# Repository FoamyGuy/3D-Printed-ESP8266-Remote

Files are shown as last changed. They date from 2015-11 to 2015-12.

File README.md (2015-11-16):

# 3D Printed Box for ESP8266 Remote Control

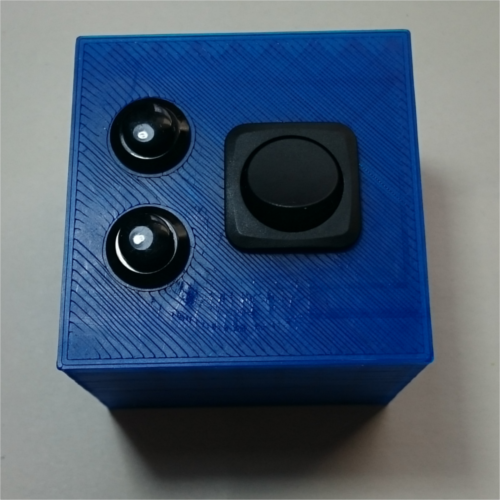
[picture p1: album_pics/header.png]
Main Image


[Picture Album](http://imgur.com/a/LUhH1)

This is a little box I designed to hold an ESP8266 powered remote control. It features 2 buttons, an on/off switch, and a 3v CR123A battery.

### Parts List:
- Box
- Lid
- Divider Plate
- Smallish Piece of Proto-board
- Braided copper wire
- CR123A 3v Battery
- Copper tape
- ESP8266
- 2x Brass 8-32 Threaded Inserts
- 2x 8-32 Machine screws 3/8" length

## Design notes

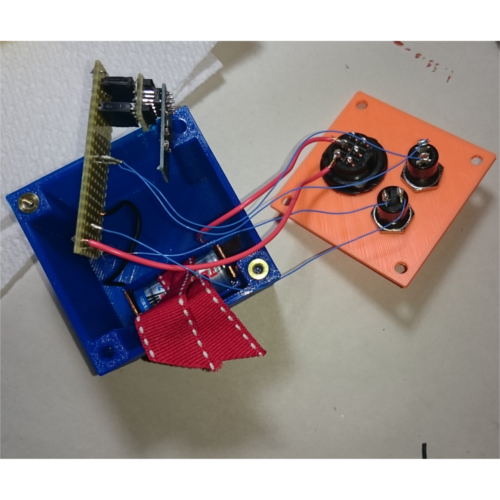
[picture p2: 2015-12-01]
album_pics/2_part_design.png

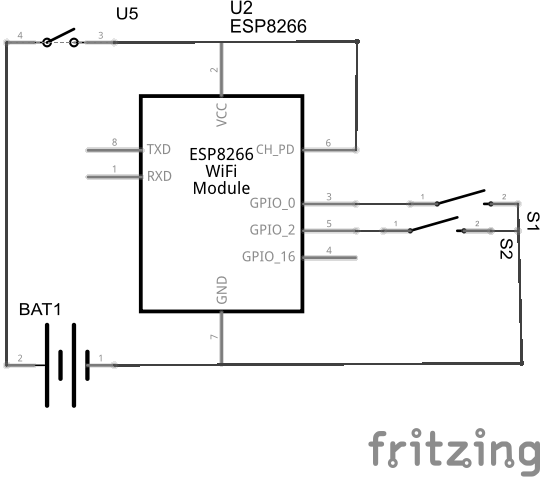
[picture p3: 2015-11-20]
album_pics/schematic.png

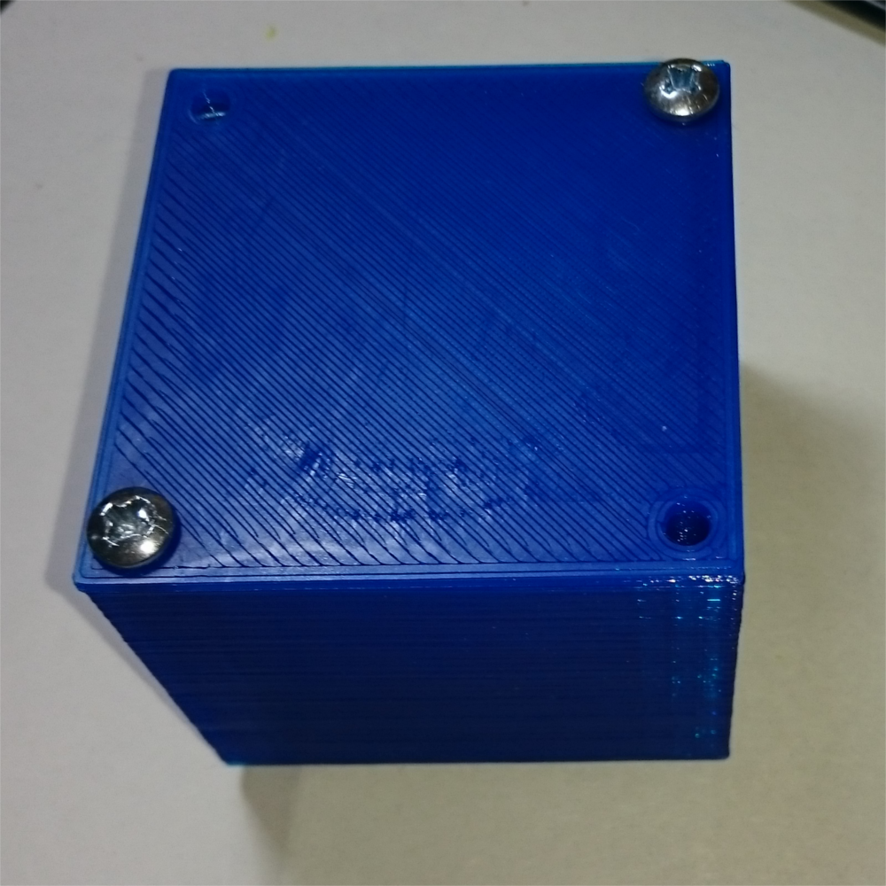
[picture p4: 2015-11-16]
album_pics/with_lid.png

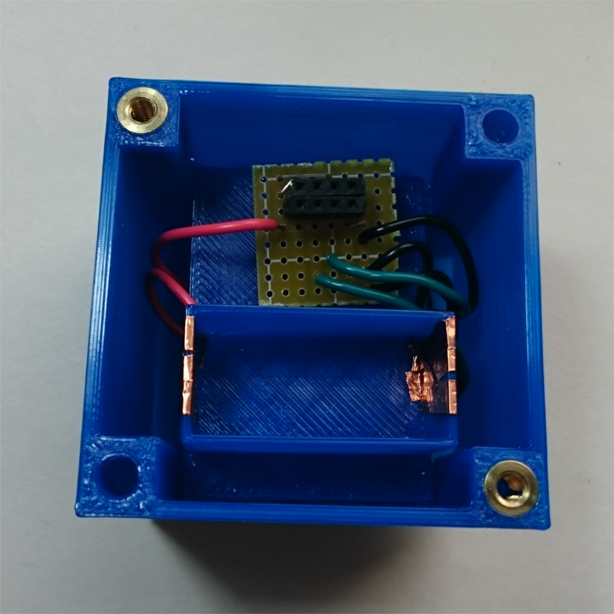
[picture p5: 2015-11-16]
album_pics/battery_conteacts_board.png

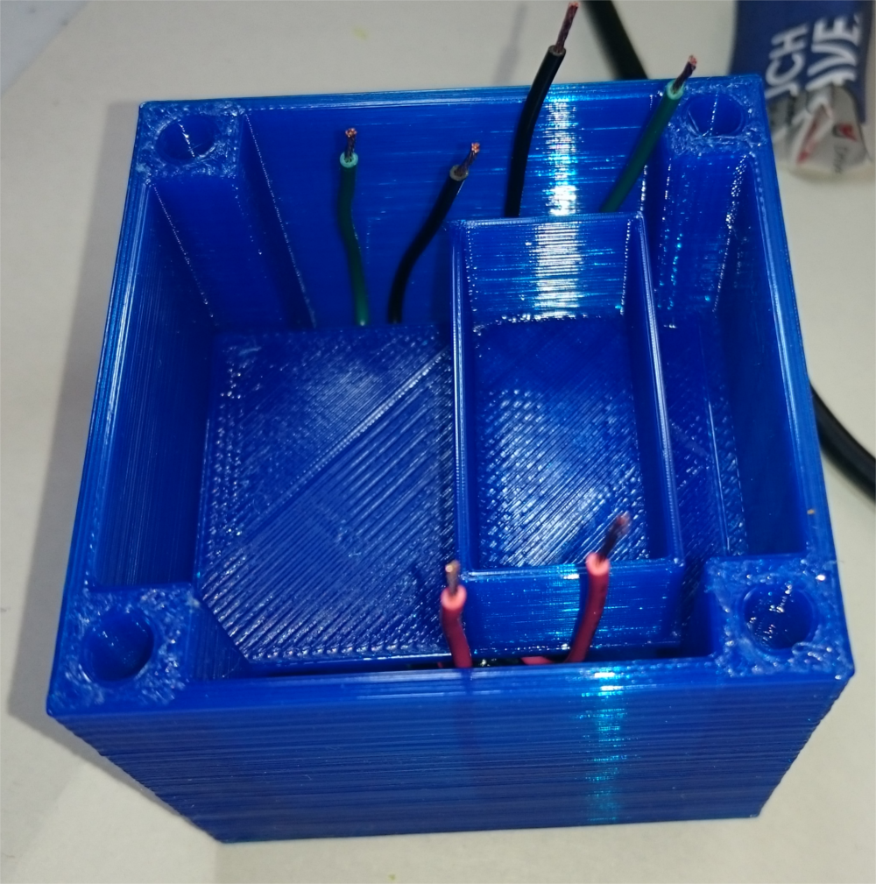
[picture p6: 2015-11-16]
album_pics/divider_in.png

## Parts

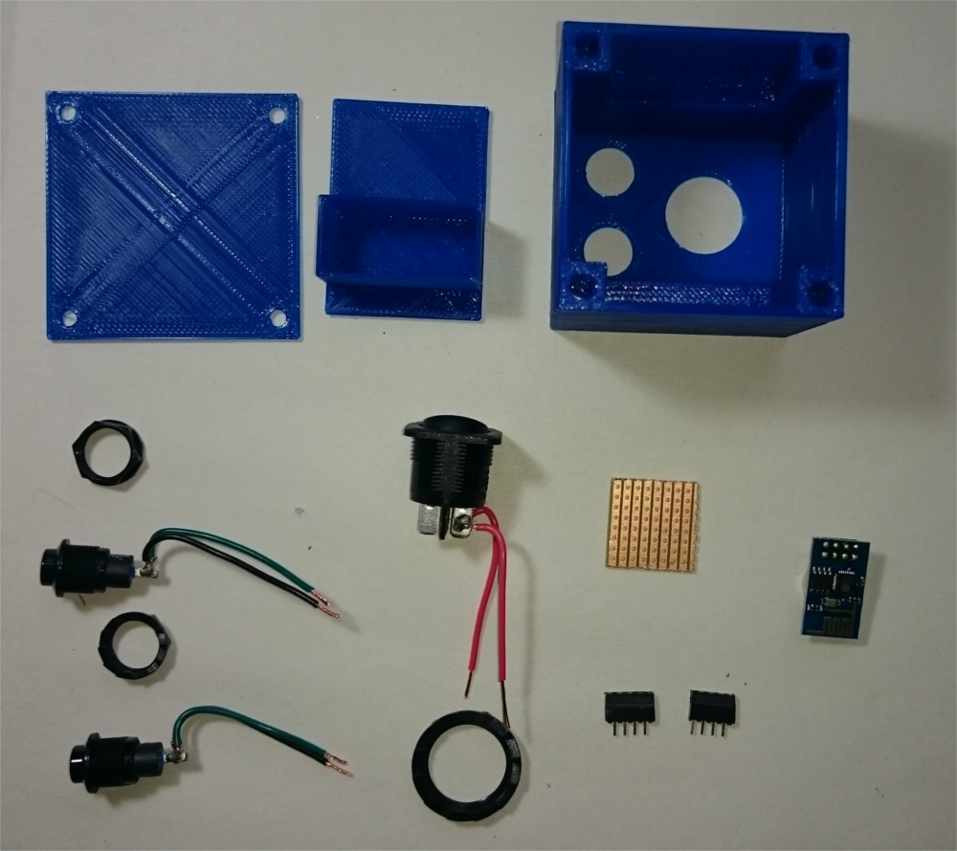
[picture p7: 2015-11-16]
album_pics/parts.png

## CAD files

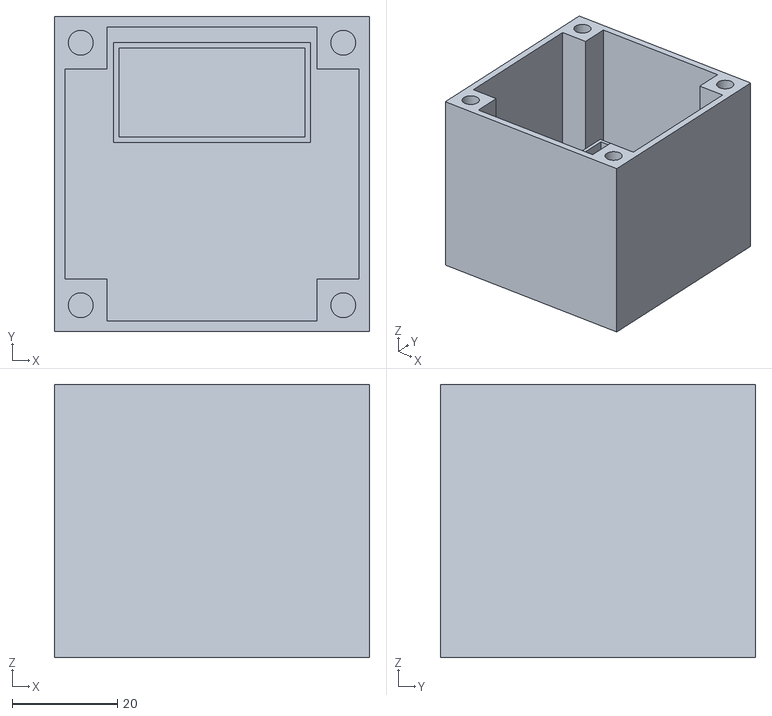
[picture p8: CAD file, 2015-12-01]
esp_box_v3.stl
60.0 x 60.0 x 52.0

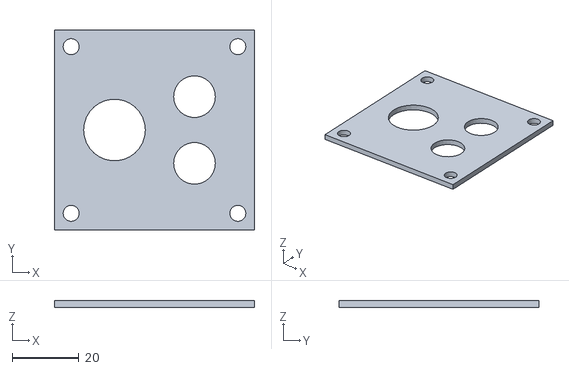
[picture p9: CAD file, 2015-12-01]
esp_box_v3_lid.stl
60.0 x 60.0 x 2.00

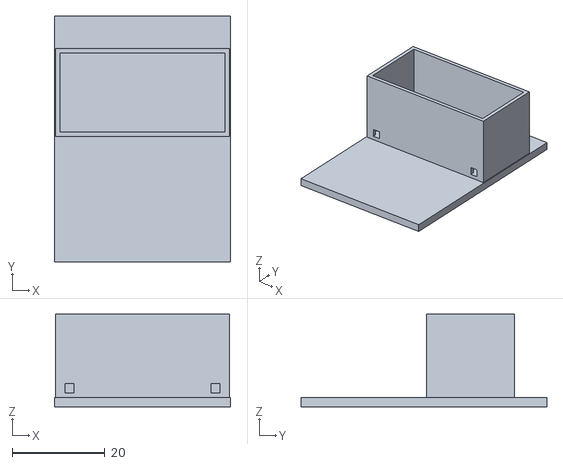
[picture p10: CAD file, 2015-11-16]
esp_box_divider.stl
38.0 x 53.0 x 20.0

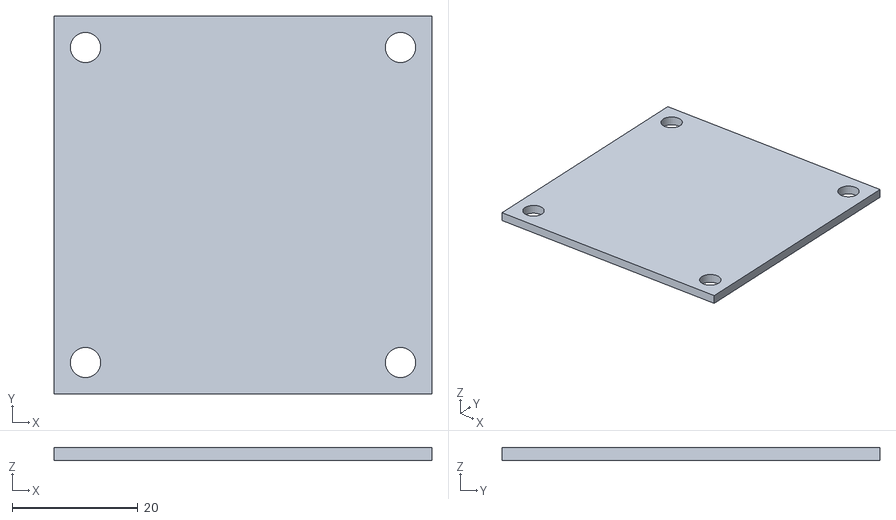
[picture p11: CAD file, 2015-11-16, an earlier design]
esp_box_lid.stl
60.0 x 60.0 x 2.00

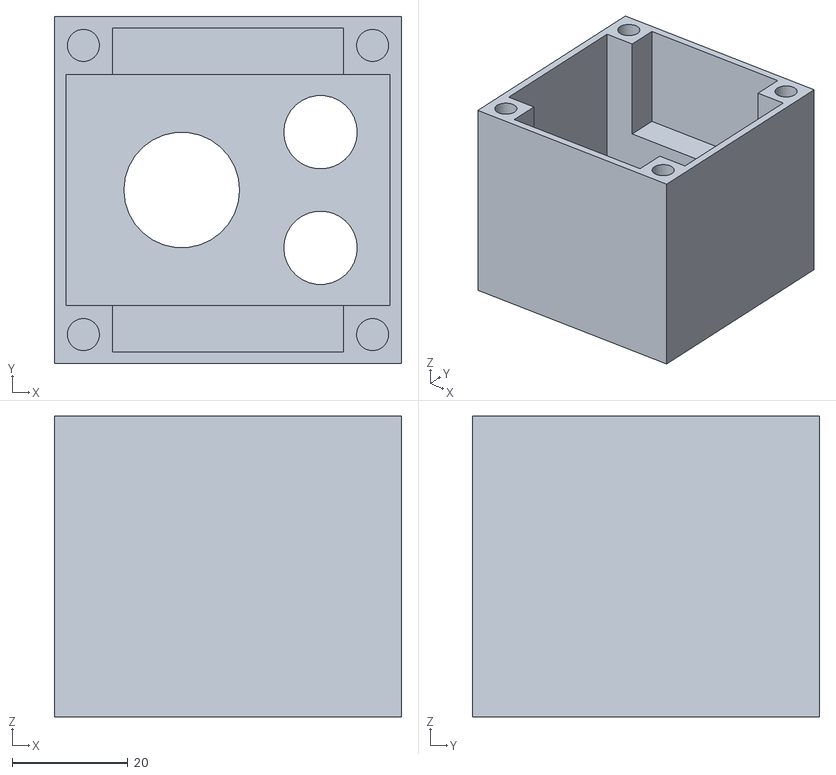
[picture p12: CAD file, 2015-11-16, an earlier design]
esp_box.stl
60.0 x 60.0 x 52.0

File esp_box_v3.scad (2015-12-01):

/**************************************************
    Variables
***************************************************/
$fn=30;

WALL_THICKNESS = 2;
BOTTOM_THICKNESS = 1;

POST_SIZE = 15;

BOARD_X = 30;
BOARD_Y = 60;
BOARD_Z = 18;

BOX_X = 60;
BOX_Y = 60;
BOX_Z = 52;

BAT_Y = 19;
BAT_X = 37.5;
BAT_Z = 19;

SWITCH_DRILL_DIAMETER = 18.5;
BUTTON_DRILL_DIAMETER = 12.5;

STANDOFF_SIZE = 10;

DIVIDER_STANDOFF_HEIGHT = 25;

INSERT_DRILL_DIAMETER = 4.7625;

/**************************************************
    Modules
***************************************************/

module box_bottom(l, w, h, wall_thickness=1, bottom_thickness=1){
    difference(){
        cube([l,w,h], center=true);
        translate([0,0,bottom_thickness])
            cube([l-(wall_thickness*2),w-(wall_thickness*2),h], center=true);
    
        //window to see in.
        //translate([0, w/2, h/2-2])cube([l-2, wall_thickness + 3, 34], center=true);
    }
}

module insert_post(h=10){
    difference(){
        cube([STANDOFF_SIZE, STANDOFF_SIZE, h], center=true);
        //translate([0,0, -h/2])cylinder(h=h, d=15);
        translate([0,0, (h/2)-12])cylinder(r=INSERT_DRILL_DIAMETER/2, h=12);
    }

}

module all_posts(BOX_X, BOX_Y, BOX_Z, wall_thickness=2){
    
    translate([BOX_X/2 - STANDOFF_SIZE/2, 
               BOX_Y/2 - STANDOFF_SIZE/2, 0])
        insert_post(BOX_Z);
    
    translate([-BOX_X/2 + STANDOFF_SIZE/2, 
               -BOX_Y/2 + STANDOFF_SIZE/2, 0])
        insert_post(BOX_Z);
    
    translate([-BOX_X/2 + STANDOFF_SIZE/2, 
               BOX_Y/2 - STANDOFF_SIZE/2, 0])
        insert_post(BOX_Z);
    
    translate([BOX_X/2 - STANDOFF_SIZE/2, 
               -BOX_Y/2 + STANDOFF_SIZE/2, 0])
        insert_post(BOX_Z);
}



module lid(l,w,h, wall_thickness=1){
    translate([0,0, h/2 + 3])
        cube([l, w,2],center=true);
}


module top_screw_holes(){
    
    SCREW_HOLE_DIAMETER = 4.8;
    
    translate([BOX_X/2 - STANDOFF_SIZE/2,
               BOX_Y/2 - STANDOFF_SIZE/2, 0])
        cylinder(r=SCREW_HOLE_DIAMETER/2, h=BOX_Z+10);
    
    translate([-BOX_X/2 + STANDOFF_SIZE/2, 
               -BOX_Y/2 + STANDOFF_SIZE/2, 0])
        cylinder(r=SCREW_HOLE_DIAMETER/2, h=BOX_Z+10);
    
    translate([-BOX_X/2 + STANDOFF_SIZE/2, 
               BOX_Y/2 - STANDOFF_SIZE/2, 0])
        cylinder(r=SCREW_HOLE_DIAMETER/2, h=BOX_Z+10);
    
    translate([BOX_X/2 - STANDOFF_SIZE/2, 
               -BOX_Y/2 + STANDOFF_SIZE/2, 0])
        cylinder(r=SCREW_HOLE_DIAMETER/2, h=BOX_Z+10);
}


module board(){
    cube([BOARD_X,BOARD_Y,BOARD_Z], center=true);
}

module switch_hole(){
   cylinder(r=SWITCH_DRILL_DIAMETER/2, h=BOX_Z + 100, center=true);
}

module button_hole(){
    cylinder(r=BUTTON_DRILL_DIAMETER/2, h=BOX_Z + 100, center=true);
}

module battery_holder(){
    difference(){
        cube([BAT_X, BAT_Y, BAT_Z], center=true);
        translate([0,0,1.01]){
            cube([BAT_X-2,BAT_Y-2,BAT_Z-2], center=true);
            
        }
        
        translate([(BAT_X/2)-3,-10,BAT_Z/2 - 4]){
            cube([2,BAT_Y/2,2], center=true);
        }
        
        translate([0-(BAT_X/2)+3,-10,BAT_Z/2 - 4]){
            cube([2,BAT_Y/2,2], center=true);
        }
    }   
}

module divider_standoffs(){
    Y_DISTANCE = ((BOX_Y/2)-(STANDOFF_SIZE/2));
    Z_DISTANCE = (-1*(BOX_Z/2) + (DIVIDER_STANDOFF_HEIGHT/2) + BOTTOM_THICKNESS);
    translate([0,Y_DISTANCE,Z_DISTANCE]){
        cube([(BOX_X-(2*STANDOFF_SIZE)),STANDOFF_SIZE,DIVIDER_STANDOFF_HEIGHT], center=true);
    }
    
    
    translate([0,-Y_DISTANCE,Z_DISTANCE]){
        cube([(BOX_X-(2*STANDOFF_SIZE)),STANDOFF_SIZE,DIVIDER_STANDOFF_HEIGHT], center=true);
    }
    
    
}

module divider_plate(){
    PLATE_X = BOX_X - (2 * STANDOFF_SIZE) - 2;
    cube([PLATE_X,BOX_Y-(2*WALL_THICKNESS)-3,2], center=true);
    translate([0,10,(BAT_Z/2)]){
        battery_holder();
    }
}





/**************************************************
    Render
***************************************************/

difference(){
    box_bottom(BOX_X, BOX_Y, BOX_Z, wall_thickness=WALL_THICKNESS, bottom_thickness=BOTTOM_THICKNESS);
    
    
    //window
    //cube([BOX_X+1,60,50], center=true);
    
}



//divider_standoffs();

translate([0,(BOX_Y/2)-(BAT_Y/2)-5, -(BOX_Z/2) + (BAT_Z/2)]){
	battery_holder();
}
all_posts(BOX_X, BOX_Y, BOX_Z, wall_thickness=WALL_THICKNESS);


/*
difference(){
    lid(BOX_X, BOX_Y, BOX_Z, wall_thickness=2);
    top_screw_holes();
    
    translate([-12,0,0]){
        switch_hole();
    }
    translate([12,10,0]){
        button_hole();
    }
    
    translate([12,-10,0]){
        button_hole();
    }
}*/

/*
translate([0,0,(BOX_Z/2)-20]){
    divider_plate();
}
*/

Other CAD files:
esp_box.scad

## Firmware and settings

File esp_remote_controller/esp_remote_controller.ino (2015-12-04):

/*
 *  This sketch joins a pre-defined wifi network. 
 *  It listens for button presses on IO pins 0 and 2.
 *  When a button is pressed it will send an HTTP GET request
 *  to a pre-defined URL.
 *
 */

#include <ESP8266WiFi.h>

// Fill in your own network info
const char* ssid     = "YourNetworwSSID";
const char* password = "YourNetworkPassword";


// Change the host and port to suite your needs.
const char* HOST = "192.168.1.104";
const int PORT = 5000;

// set the endpoints for each button.
String BTN_1_TRIGGER_URL = "/team2";
String BTN_0_TRIGGER_URL = "/team1";

String BTN_1_LONG_PRESS_TRIGGER_URL = "/team2minus";
String BTN_0_LONG_PRESS_TRIGGER_URL = "/team1minus";

// endpoint for hello action. Gets called once at end of startup.
 String HELLO_URL = "/hello";

// endpoint for 'poke' action that controller will send after
// 5 minutes of inactivity.
String POKE_URL = "/poke";

int BTN_1_PIN = 2;
int BTN_0_PIN = 0;

int BTN_1_PREV = HIGH;
int BTN_0_PREV = HIGH;


unsigned long BTN_1_DOWN_TIME = 0;
unsigned long BTN_0_DOWN_TIME = 0;

unsigned long time_of_press = 0;
unsigned long cur_time = 0;

void http_get(const char* host, int port, String url){
     // Use WiFiClient class to create TCP connections
  WiFiClient client;
  const int httpPort = port;
  if (!client.connect(host, httpPort)) {
    Serial.println("connection failed");
    return;
  }
  Serial.print("Requesting URL: ");
  Serial.println(url);
  
  // This will send the request to the server
  client.print(String("GET ") + url + " HTTP/1.1\r\n" +
               "Host: " + host + "\r\n" + 
               "Connection: close\r\n\r\n");
  delay(10);
  
  // Read all the lines of the reply from server and print them to Serial
  while(client.available()){
    String line = client.readStringUntil('\r');
    Serial.print(line);
  }
  
  Serial.println();
  Serial.println("closing connection");
}

void setup() {
  Serial.begin(115200);
  delay(10);

  // We start by connecting to a WiFi network

  Serial.println();
  Serial.println();
  Serial.print("Connecting to ");
  Serial.println(ssid);
  
  WiFi.begin(ssid, password);
  
  while (WiFi.status() != WL_CONNECTED) {
    delay(500);
    Serial.print(".");
  }

  Serial.println("");
  Serial.println("WiFi connected");  
  Serial.println("IP address: ");
  Serial.println(WiFi.localIP());

  pinMode(BTN_1_PIN, INPUT_PULLUP);
  pinMode(BTN_0_PIN, INPUT_PULLUP);

  // say hi
  if (HELLO_URL != ""){
    http_get(HOST, PORT, HELLO_URL);
  }
  
}

void loop() {
  int cur1 = digitalRead(BTN_1_PIN);
  int cur0 = digitalRead(BTN_0_PIN);

  /* 
   *  check if buttons were pressed down 
   */
  if ((cur1 == LOW) && (BTN_1_PREV == HIGH)){
    time_of_press = millis();
    BTN_1_DOWN_TIME = time_of_press;
  }

  if ((cur0 == LOW) && (BTN_0_PREV == HIGH)){
    time_of_press = millis();
    BTN_0_DOWN_TIME = time_of_press;
  }

  /*
   * check if buttons were released
   */

  if ((cur1 == HIGH) && (BTN_1_PREV == LOW)){
    // Determine if long press or short press
    cur_time = millis();
    if((cur_time - BTN_1_DOWN_TIME) < 750){
      http_get(HOST, PORT, BTN_1_TRIGGER_URL);
    }
  }

  if ((cur0 == HIGH) && (BTN_0_PREV == LOW)){
    // Determine if long press or short press
    cur_time = millis();
    if((cur_time - BTN_0_DOWN_TIME) < 750){
      http_get(HOST, PORT, BTN_0_TRIGGER_URL);
    }
  }

  /* Check if buttons have been held down 
   *  
   */

   cur_time = millis();
   
   if ((cur0==LOW) && ((cur_time - BTN_0_DOWN_TIME) > 750)){
      time_of_press = millis();
      http_get(HOST, PORT, BTN_0_LONG_PRESS_TRIGGER_URL);
   }
   if ((cur1==LOW) && ((cur_time - BTN_1_DOWN_TIME) > 750)){
      time_of_press = millis();
      http_get(HOST, PORT, BTN_1_LONG_PRESS_TRIGGER_URL);
   }


  BTN_1_PREV = cur1;
  BTN_0_PREV = cur0;

  // Check idle time. Send poke action.
  if ((cur_time - time_of_press) > (1000 * 60 * 5) && (time_of_press > 0)){
    http_get(HOST, PORT, POKE_URL);

    // poke again in 1min
    time_of_press = time_of_press + (1000 * 60);
  }
  
  delay(100);
}

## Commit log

2015-11-16 adding esp arduino IDE code.
2015-11-20 adding circuit diagram
2015-12-01 adding v3 design files and pictures
    [circut.fzz, esp_box_v3.scad, esp_box_v3.stl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]
2015-12-02 adding longpress and hello actions to the esp arduino code
2015-12-04 adding poke action to arduino code
